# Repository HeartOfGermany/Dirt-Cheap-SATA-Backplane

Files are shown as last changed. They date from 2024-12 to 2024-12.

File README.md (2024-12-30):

# Dirt-Cheap-SATA-Backplane

## Front side (left/first) and back side

<picture>
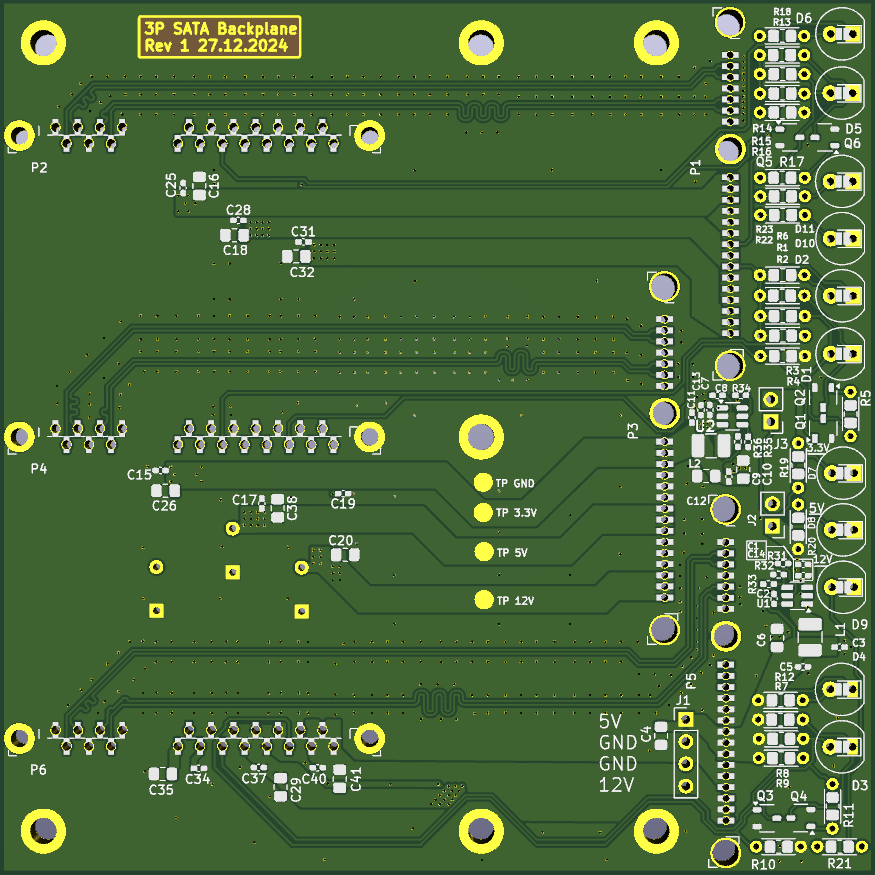
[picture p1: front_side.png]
Front side of the SATA Backplane
  
</picture>
<picture>
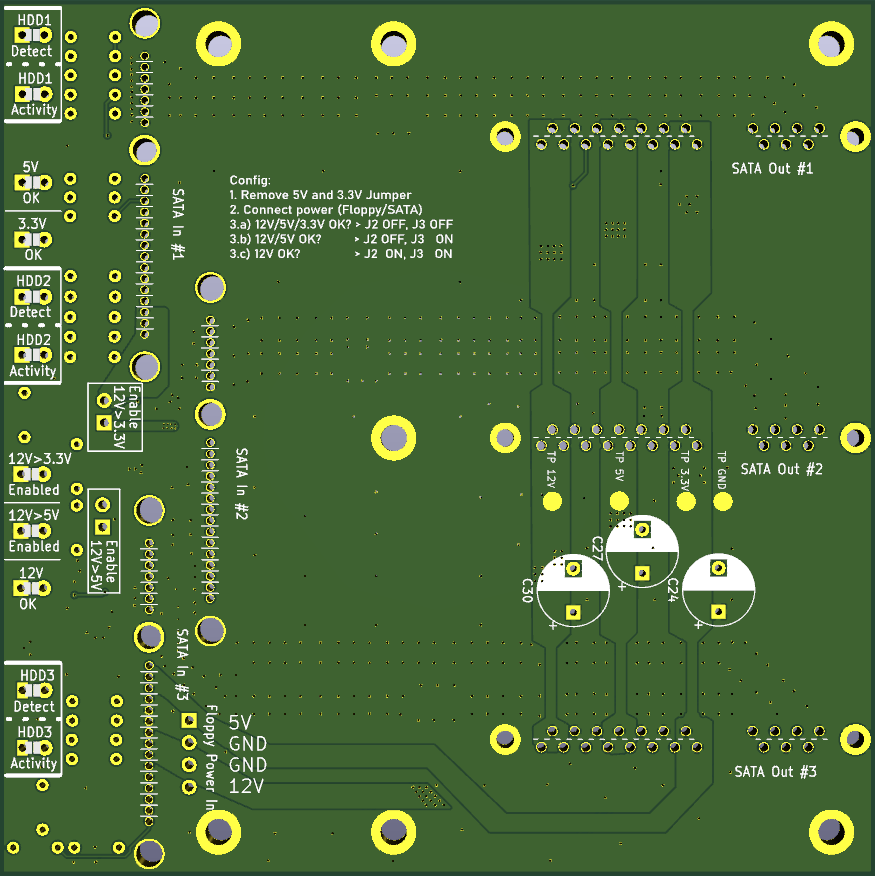
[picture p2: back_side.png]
Back side of the SATA Backplane
  
</picture>

This repo is intended to share plans for a super cheap DIY backplane. It is using KiCad and it fits the 100x100mm default of JLCPCB

Example: 100x100mm PCB x10pcs costs 15€ delivered to europe as the time of writing this. So 1 Backplane PCB costs just 1.50€ plus components. It uses 1.6mm 2 layer FR4.

## Features:
- LED Indicators
  - Activity LED (Bi-Color support!)
  - HDD Detect LED
  - 12V Power OK
  - 5V Power OK
  - 3.3V Power OK
  - 5V Power generator activated
  - 3.3V Power generator activated
- SATA or Floppy power input (or just solder your custom cable)
  - 12V only input (generate 5V and 3.3V automatically)
  - 12V+5V input (generate 3.3V automatically)
- Optional components
  - Do not need certain Indicators? Than leave them out
  - Do not need 5V or 3.3V generation? Than just do not solder in the converters
  - Just want to solder THT and NO SMD? Can do just that (But Activity LED requires 2 SOT23 transistors - but easier to solder than TO-92!
  - Just want to solder SMD? Also fine!
  - LED indicators to back side or front side? Do as you wish
  - Do not want to solder tons of decoupling? Just leave it out. It is optional and I only use the caps in the converter section of the schematic 

## How to use?
Steps:
1. Develop the board (JLCPCB worked fine for me)
2. Meanwhile order the Components, check the Schematic for purchasing links (no affiliate!)
3. Solder the components as you like
4. Test with an old HDD first!
5. Design some enclosure or cage, where you can screw the PCB onto the backside to slide it in and out again. After all... it is a Hot-Swap SATA Backplane. I used some wooden boards from an old drawer with some cut slots and a laser to get some ventilation slots. Than I used thin ply wood to mount the HDDs on (3mm max. recommended). These ply wood plates can slide in and out on the slotted boards, which form the surrounding. The uplink connectors are on the outside of the board. I will see if I will attach a reference image... Use your brain, it's not hard to build stuff!
6. How to nail alignment? The PCB has some mounting holes. Get yourself some flat standoffs and screw them in. Use some Alc to clean the backplate and the standoffs for adheasion. Now plug an upper and lower HDD in at least, to get the proper alignment. Use a dab of epoxy and just lay it on the backplate. The standoffs will glue in over the course of 24h (some gentle heat like 40-50°C speeds up a lot!) and you can than mount and unmount this as often by just unscrewing the screws (remember: after on comes off, so do not overtorque!). I recommend adding another layer to reinforce the joint and maybe even roughen the standoffs for better adheason, aswell as adding filler like quarz sand to the epoxy, to get a dang resilient, thick bond.

## Attention:
**DO**
- Use Flux. Tons of flux. If you are too cheap, use at least some Rosin intended for inhalation - it comes in 100g bags for just 2-3 bucks and is more efficient than those tiny containers with like 10g rosin.
- How to clean the flux residue easily? Use denatured Alc or Isopropyl to soak and than clean the board. You can also soak the board by wrapping in toilet paper and soaking it in Alc and leav it over night in a bag. Next day use tooth brush and carefully mobilize the rest of residues. Use some more to wash the rest away and your board will look like from factory
- Use enough heat! I make a lot of use of ground planes. Heat joints as fast as possible and go away to not damage components
- SATA connectors are hard to find on many proper stores, I got mine from Aliexpress - just double check the images to the PCB before ordering. The PCB allows some variation (Holes larger than needed). In theory you could also solder SMD equivalents in, if you can find some
- The Schematic contains a section "Parts List". A lot is from LCSC from China. It is like a dirt cheap Mouser/Digikey alternative, but of amazing quality. If you are cheap but want to ensure original components only, go there for your parts!
- Consider a Bismuth solder and some Amtech 559, if you are new to soldering. Requiring like 50K less temperature helps a LOT. It gives a ton of time to work on joints and constantly reflow, without overheating components (Especially ceramic caps are sensitive to re-heating a lot - could short)

**DON'T**
- Do not enable 3.3V or 5V generation, if your power input already supplies it! Check with the Voltage OK LEDs first! Otherwise the tiny buck converters try to provide 5V and 3.3V to your PC, which they cannot handle and they WILL overheat, potentially with permanent damage to the PCB.
- Do not use other thicknesses or materials than 1.6mm FR4!!! These could mess with the differential pair signalling, as the ground plane distance is very important to keep proper impedance
- Do NOT forget to use tons of flux. The PCB is easy to solder, if you use a decent cheap 60€/$ solder station with hot air, if Flux and Solder are good. Leaded solder helps a lot (though not healthy), or bismuth solder. Bismuth solder is a lot more brittle. Ensure, that the fillets form perfectly or rework them before use.

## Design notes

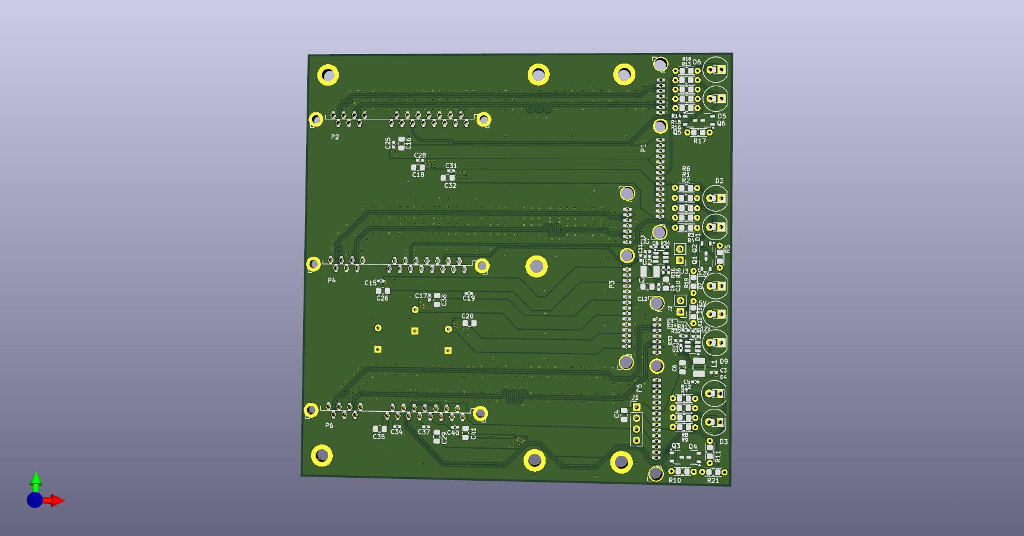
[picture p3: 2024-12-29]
sata_backplane.jpg

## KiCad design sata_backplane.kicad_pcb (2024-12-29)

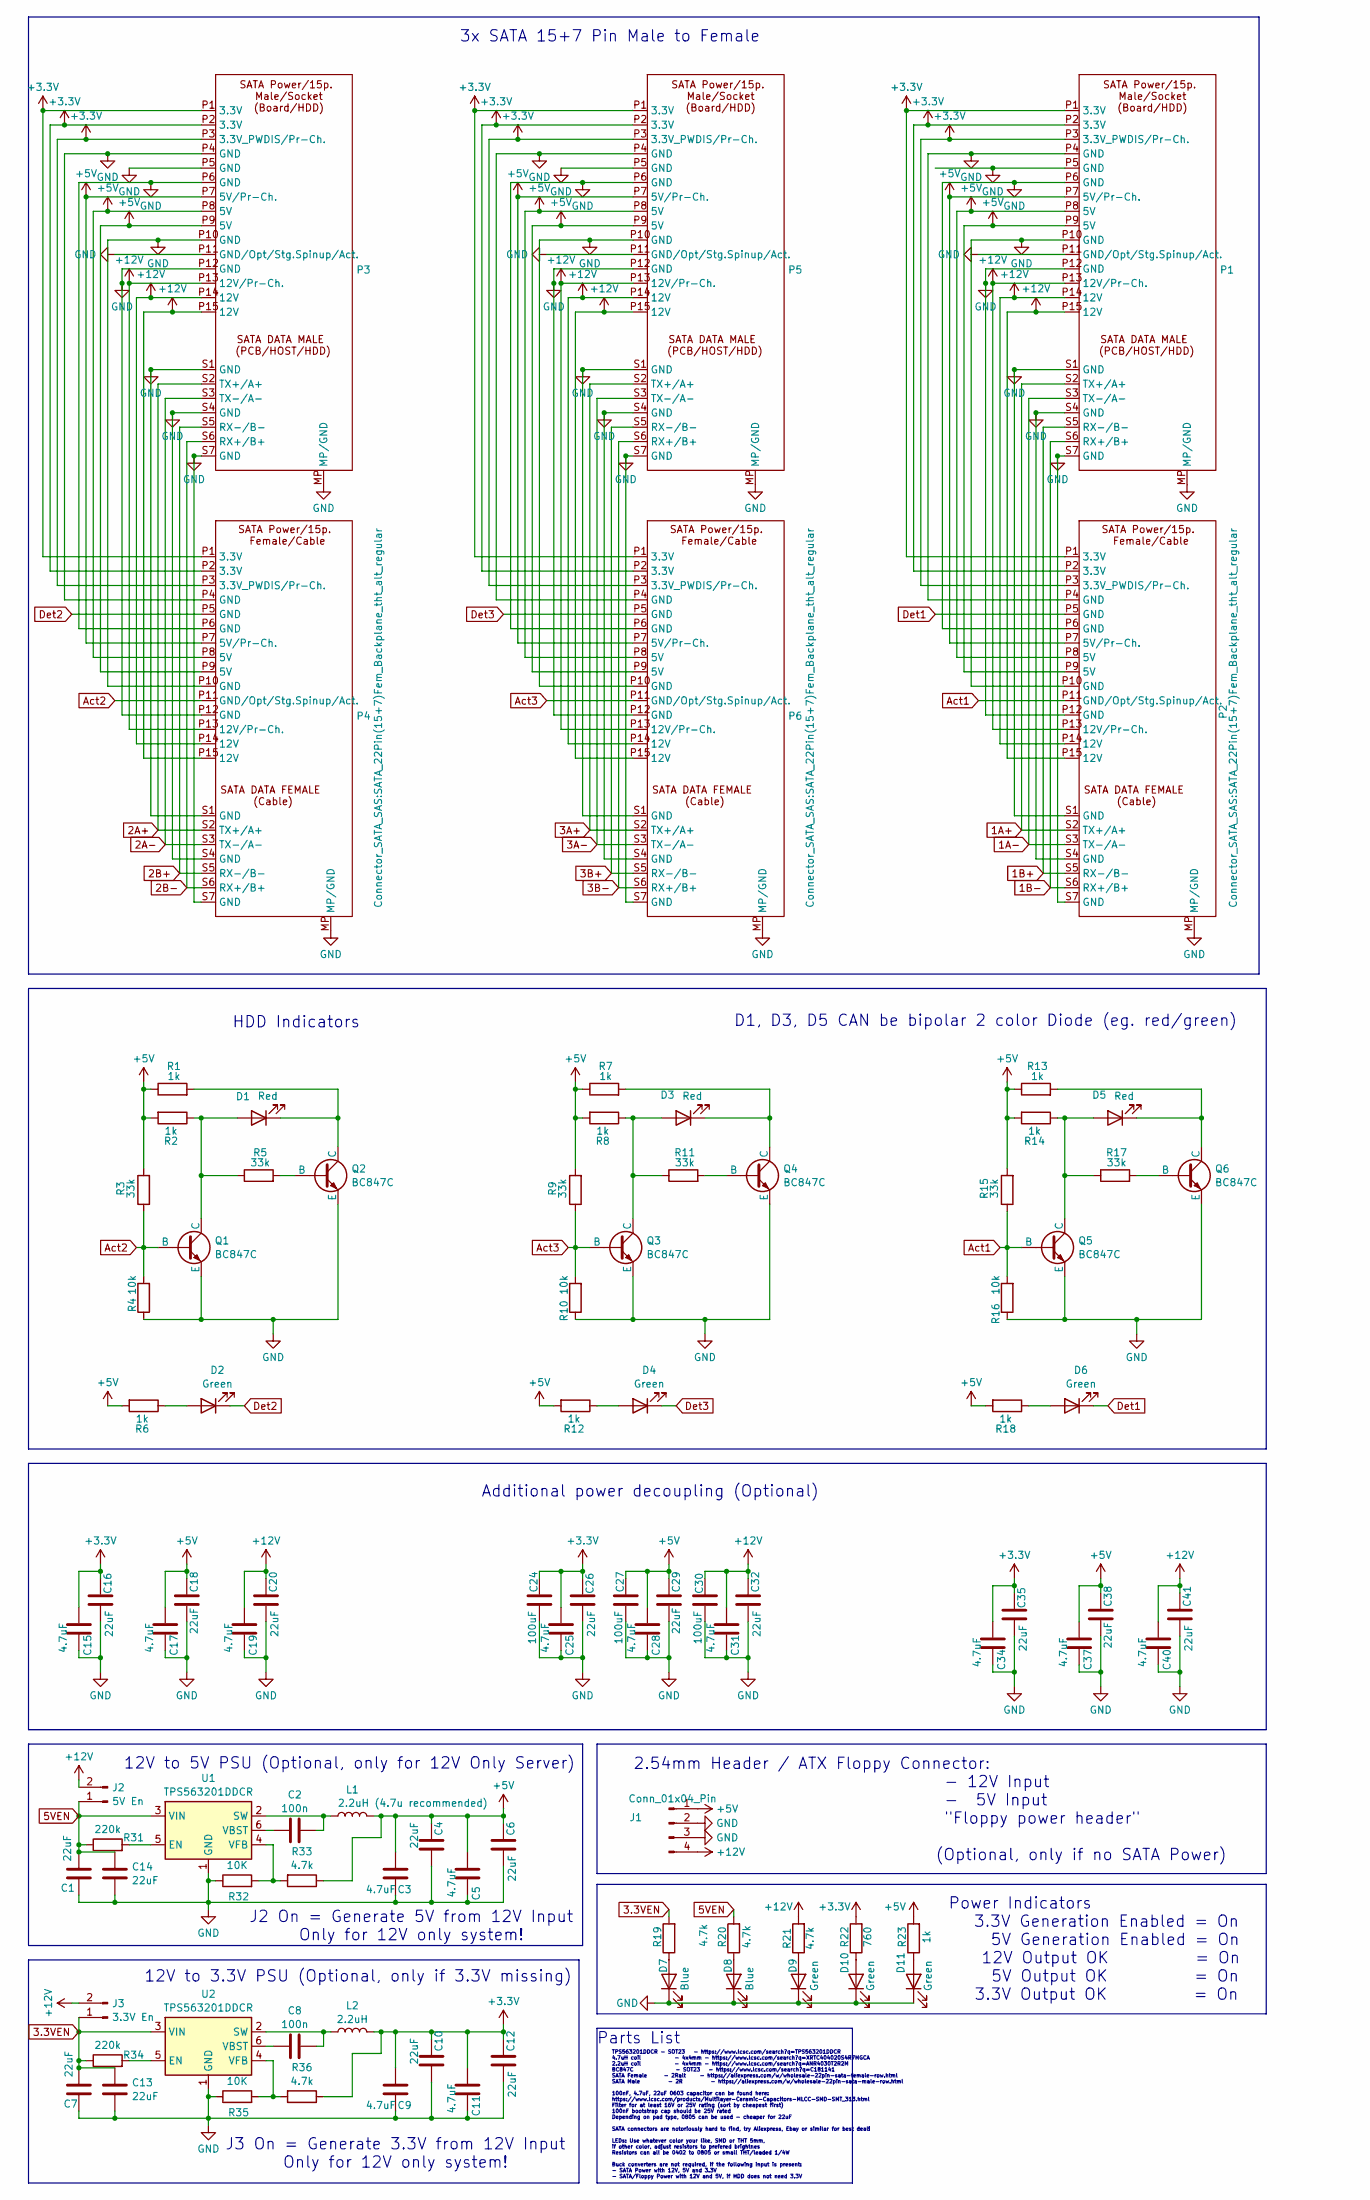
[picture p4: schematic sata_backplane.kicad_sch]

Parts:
C1, C7, C13, C14: 22uF; C_0402_1005Metric_Pad0.74x0.62mm_HandSolder
C2, C8: 100n; C_0402_1005Metric_Pad0.74x0.62mm_HandSolder
C3, C5, C9, C11, C15, C17, C19, C25, C28, C31, C34, C37, C40: 4.7uF; C_0402_1005Metric_Pad0.74x0.62mm_HandSolder
C4, C6, C10, C12, C16, C18, C20, C26, C29, C32, C35, C38, C41: 22uF; C_0805_2012Metric_Pad1.18x1.45mm_HandSolder
C24, C27, C30: 100uF; CP_Radial_D8.0mm_P5.00mm
D1, D3, D5: Red; Diode_SMD_THT_5mm_combi
D2, D4, D6, D9, D10, D11: Green; Diode_SMD_THT_5mm_combi
D7, D8: Blue; Diode_SMD_THT_5mm_combi
J1: Conn_01x04_Pin; PinHeader_1x04_P2.54mm_Vertical
J2: 5V En; PinHeader_1x02_P2.54mm_Vertical
J3: 3.3V En; PinHeader_1x02_P2.54mm_Vertical
L1: 2.2uH (4.7u recommended); L_1210_3225Metric_Pad1.42x2.65mm_HandSolder
L2: 2.2uH; L_1210_3225Metric_Pad1.42x2.65mm_HandSolder
P1, P3, P5: SATA_22Pin(15+7)Fem_Backplane_tht_lin
P2, P4, P6: SATA_22Pin(15+7)Fem_Backplane_tht_alt_regular
Q1, Q2, Q3, Q4, Q5, Q6: BC847C; SOT-23-3-Correct
R1, R2, R6, R7, R8, R12, R13, R14, R18, R23: 1k; R_Axial_L3.6_D1.6_P5.08_0805SMD_Combi
R3, R5, R9, R11, R15, R17: 33k; R_Axial_L3.6_D1.6_P5.08_0805SMD_Combi
R4, R10, R16: 10k; R_Axial_L3.6_D1.6_P5.08_0805SMD_Combi
R19, R20, R21: 4.7k; R_Axial_L3.6_D1.6_P5.08_0805SMD_Combi
R22: 760; R_Axial_L3.6_D1.6_P5.08_0805SMD_Combi
R31, R34: 220k; R_0402_1005Metric_Pad0.72x0.64mm_HandSolder
R32, R35: 10K; R_0402_1005Metric_Pad0.72x0.64mm_HandSolder
R33, R36: 4.7k; R_0402_1005Metric_Pad0.72x0.64mm_HandSolder
U1, U2: TPS563201DDCR; SOT-23-6

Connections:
1A+: P1.S2 (TX+/A+), P2.S2 (TX+/A+)
1A-: P1.S3 (TX-/A-), P2.S3 (TX-/A-)
1B+: P1.S5 (RX-/B-), P2.S5 (RX-/B-)
1B-: P1.S6 (RX+/B+), P2.S6 (RX+/B+)
2A+: P3.S2 (TX+/A+), P4.S2 (TX+/A+)
2A-: P3.S3 (TX-/A-), P4.S3 (TX-/A-)
2B+: P3.S5 (RX-/B-), P4.S5 (RX-/B-)
2B-: P3.S6 (RX+/B+), P4.S6 (RX+/B+)
3.3VEN: C7.2, C13.2, J3.1, R19.2, R34.1, U2.3 (VIN)
3A+: P5.S2 (TX+/A+), P6.S2 (TX+/A+)
3A-: P5.S3 (TX-/A-), P6.S3 (TX-/A-)
3B+: P5.S5 (RX-/B-), P6.S5 (RX-/B-)
3B-: P5.S6 (RX+/B+), P6.S6 (RX+/B+)
5VEN: C1.2, C14.2, J2.1, R20.2, R31.1, U1.3 (VIN)
+3.3V: C9.2, C10.2, C11.2, C12.2, C15.2, C16.2, C24.2, C25.2, C26.2, C34.2, C35.2, L2.2, P1.P1 (3.3V), P1.P2 (3.3V), P1.P3 (3.3V_PWDIS/Pr-Ch.), P2.P1 (3.3V), P2.P2 (3.3V), P2.P3 (3.3V_PWDIS/Pr-Ch.), P3.P1 (3.3V), P3.P2 (3.3V), P3.P3 (3.3V_PWDIS/Pr-Ch.), P4.P1 (3.3V), P4.P2 (3.3V), P4.P3 (3.3V_PWDIS/Pr-Ch.), P5.P1 (3.3V), P5.P2 (3.3V), P5.P3 (3.3V_PWDIS/Pr-Ch.), P6.P1 (3.3V), P6.P2 (3.3V), P6.P3 (3.3V_PWDIS/Pr-Ch.), R22.2, R36.1
+5V: C3.2, C4.2, C5.2, C6.2, C17.2, C18.2, C27.2, C28.2, C29.2, C37.2, C38.2, J1.1, L1.2, P1.P7 (5V/Pr-Ch.), P1.P8 (5V), P1.P9 (5V), P2.P7 (5V/Pr-Ch.), P2.P8 (5V), P2.P9 (5V), P3.P7 (5V/Pr-Ch.), P3.P8 (5V), P3.P9 (5V), P4.P7 (5V/Pr-Ch.), P4.P8 (5V), P4.P9 (5V), P5.P7 (5V/Pr-Ch.), P5.P8 (5V), P5.P9 (5V), P6.P7 (5V/Pr-Ch.), P6.P8 (5V), P6.P9 (5V), R1.1, R2.2, R3.2, R6.2, R7.1, R8.2, R9.2, R12.2, R13.1, R14.2, R15.2, R18.2, R23.2, R33.1
+12V: C19.2, C20.2, C30.2, C31.2, C32.2, C40.2, C41.2, J1.4, J2.2, J3.2, P1.P13 (12V/Pr-Ch.), P1.P14 (12V), P1.P15 (12V), P2.P13 (12V/Pr-Ch.), P2.P14 (12V), P2.P15 (12V), P3.P13 (12V/Pr-Ch.), P3.P14 (12V), P3.P15 (12V), P4.P13 (12V/Pr-Ch.), P4.P14 (12V), P4.P15 (12V), P5.P13 (12V/Pr-Ch.), P5.P14 (12V), P5.P15 (12V), P6.P13 (12V/Pr-Ch.), P6.P14 (12V), P6.P15 (12V), R21.2
Act1: P2.P11 (GND/Opt/Stg.Spinup/Act.), Q5.2 (B), R15.1, R16.2
Act2: P4.P11 (GND/Opt/Stg.Spinup/Act.), Q1.2 (B), R3.1, R4.2
Act3: P6.P11 (GND/Opt/Stg.Spinup/Act.), Q3.2 (B), R9.1, R10.2
Det1: D6.1 (K), P2.P5 (GND)
Det2: D2.1 (K), P4.P5 (GND)
Det3: D4.1 (K), P6.P5 (GND)
GND: C1.1, C3.1, C4.1, C5.1, C6.1, C7.1, C9.1, C10.1, C11.1, C12.1, C13.1, C14.1, C15.1, C16.1, C17.1, C18.1, C19.1, C20.1, C24.1, C25.1, C26.1, C27.1, C28.1, C29.1, C30.1, C31.1, C32.1, C34.1, C35.1, C37.1, C38.1, C40.1, C41.1, D7.1 (K), D8.1 (K), D9.1 (K), D10.1 (K), D11.1 (K), J1.2, J1.3, P1.MP (MP/GND), P1.P4 (GND), P1.P5 (GND), P1.P6 (GND), P1.P10 (GND), P1.P11 (GND/Opt/Stg.Spinup/Act.), P1.P12 (GND), P1.S1 (GND), P1.S4 (GND), P1.S7 (GND), P2.MP (MP/GND), P2.P4 (GND), P2.P6 (GND), P2.P10 (GND), P2.P12 (GND), P2.S1 (GND), P2.S4 (GND), P2.S7 (GND), P3.MP (MP/GND), P3.P4 (GND), P3.P5 (GND), P3.P6 (GND), P3.P10 (GND), P3.P11 (GND/Opt/Stg.Spinup/Act.), P3.P12 (GND), P3.S1 (GND), P3.S4 (GND), P3.S7 (GND), P4.MP (MP/GND), P4.P4 (GND), P4.P6 (GND), P4.P10 (GND), P4.P12 (GND), P4.S1 (GND), P4.S4 (GND), P4.S7 (GND), P5.MP (MP/GND), P5.P4 (GND), P5.P5 (GND), P5.P6 (GND), P5.P10 (GND), P5.P11 (GND/Opt/Stg.Spinup/Act.), P5.P12 (GND), P5.S1 (GND), P5.S4 (GND), P5.S7 (GND), P6.MP (MP/GND), P6.P4 (GND), P6.P6 (GND), P6.P10 (GND), P6.P12 (GND), P6.S1 (GND), P6.S4 (GND), P6.S7 (GND), Q1.3 (E), Q2.3 (E), Q3.3 (E), Q4.3 (E), Q5.3 (E), Q6.3 (E), R4.1, R10.1, R16.1, R32.1, R35.1, U1.1 (GND), U2.1 (GND)
unnamed: D1.2 (A), Q1.1 (C), R2.1, R5.1
unnamed: D1.1 (K), Q2.1 (C), R1.2
unnamed: D2.2 (A), R6.1
unnamed: D3.2 (A), Q3.1 (C), R8.1, R11.1
unnamed: D3.1 (K), Q4.1 (C), R7.2
unnamed: D4.2 (A), R12.1
unnamed: D5.2 (A), Q5.1 (C), R14.1, R17.1
unnamed: D5.1 (K), Q6.1 (C), R13.2
unnamed: D6.2 (A), R18.1
unnamed: D7.2 (A), R19.1
unnamed: D8.2 (A), R20.1
unnamed: D9.2 (A), R21.1
unnamed: D10.2 (A), R22.1
unnamed: D11.2 (A), R23.1
unnamed: Q2.2 (B), R5.2
unnamed: Q4.2 (B), R11.2
unnamed: Q6.2 (B), R17.2
unnamed: R31.2, U1.5 (EN)
unnamed: C2.1, L1.1, U1.2 (SW)
unnamed: C2.2, U1.6 (VBST)
unnamed: R32.2, R33.2, U1.4 (VFB)
unnamed: R34.2, U2.5 (EN)
unnamed: C8.1, L2.1, U2.2 (SW)
unnamed: C8.2, U2.6 (VBST)
unnamed: R35.2, R36.2, U2.4 (VFB)

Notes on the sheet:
J2 On = Generate 5V from 12V Input Only for 12V only system!
J3 On = Generate 3.3V from 12V Input Only for 12V only system!
12V to 5V PSU (Optional, only for 12V Only Server)
TPS563201DDCR - SOT23 - https://www.lcsc.com/search?q=TPS563201DDCR 4.7uH coil - 4x4mm - https://www.lcsc.com/search?q=XRTC404020S4R7MGCA 2.2uH coil - 4x4mm - https://www.lcsc.com/search?q=ANR4030T2R2M BC847C - SOT23 - https://www.lcsc.com/search?q=C181141 SATA Female - 2Ralt - https://aliexpress.c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
D1, D3, D5 CAN be bipolar 2 color Diode (eg. red/green)
HDD Indicators
Parts List
3x SATA 15+7 Pin Male to Female
12V to 3.3V PSU (Optional, only if 3.3V missing)
Power Indicators 3.3V Generation Enabled = On 5V Generation Enabled = On 12V Output OK = On 5V Output OK = On 3.3V Output OK = On
2.54mm Header / ATX Floppy Connector: - 12V Input - 5V Input "Floppy power header" (Optional, only if no SATA Power)
Additional power decoupling (Optional)

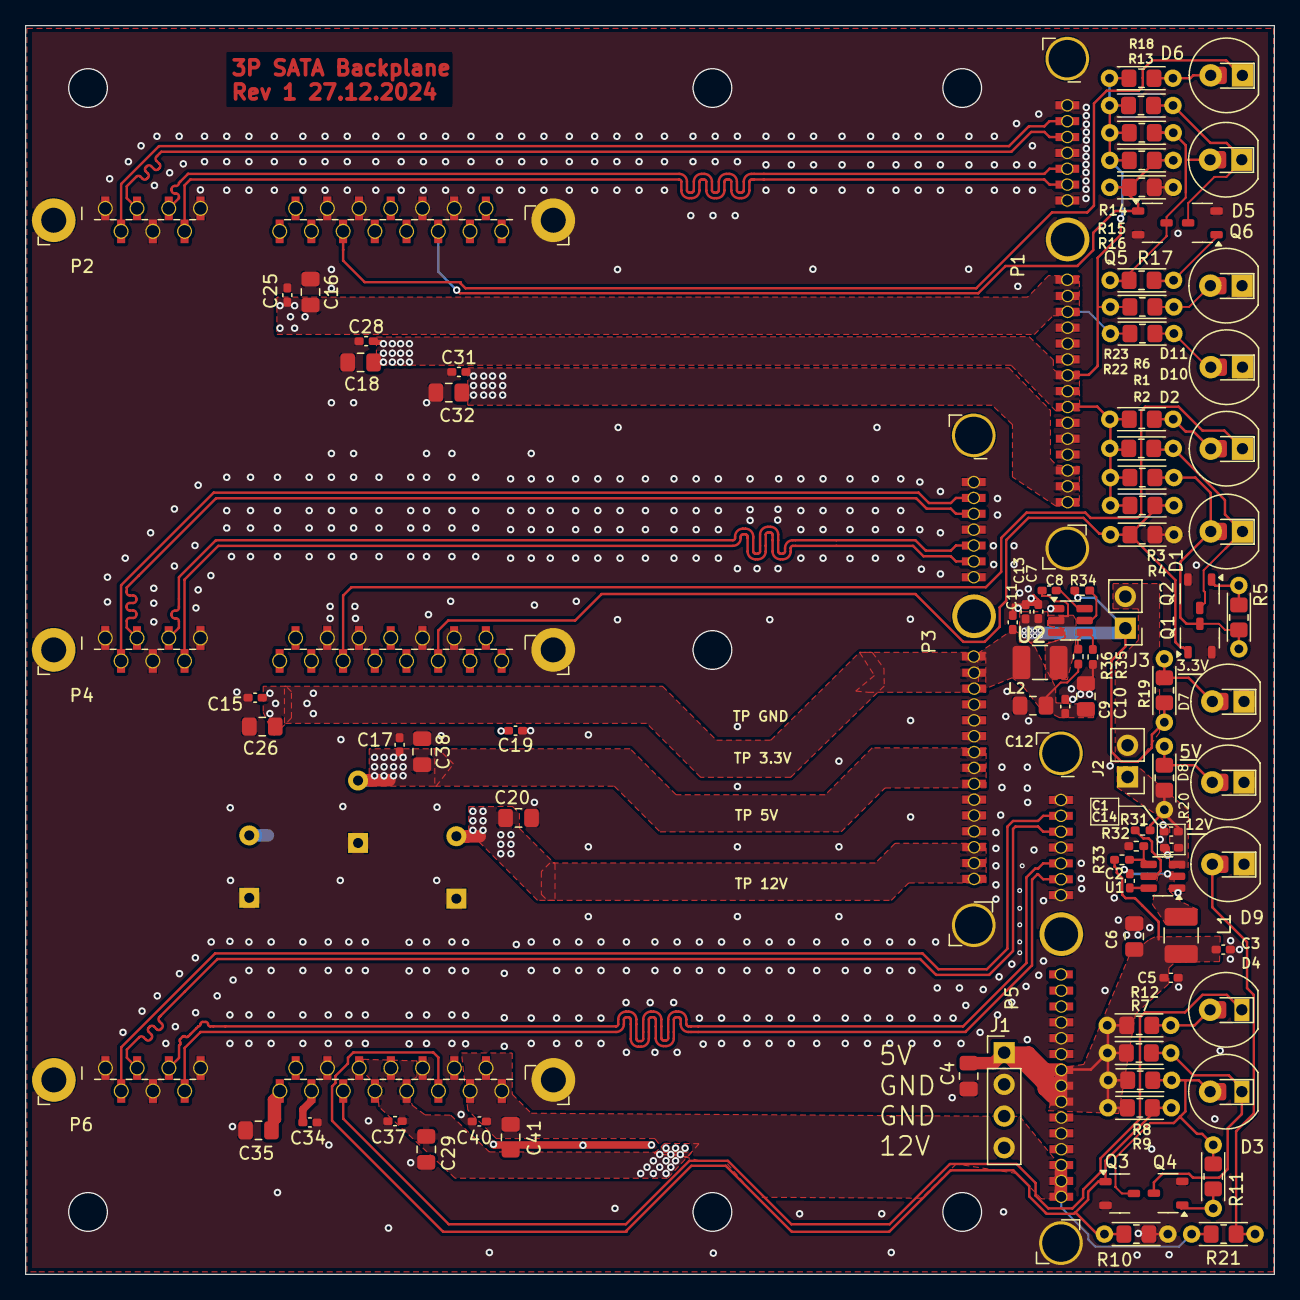
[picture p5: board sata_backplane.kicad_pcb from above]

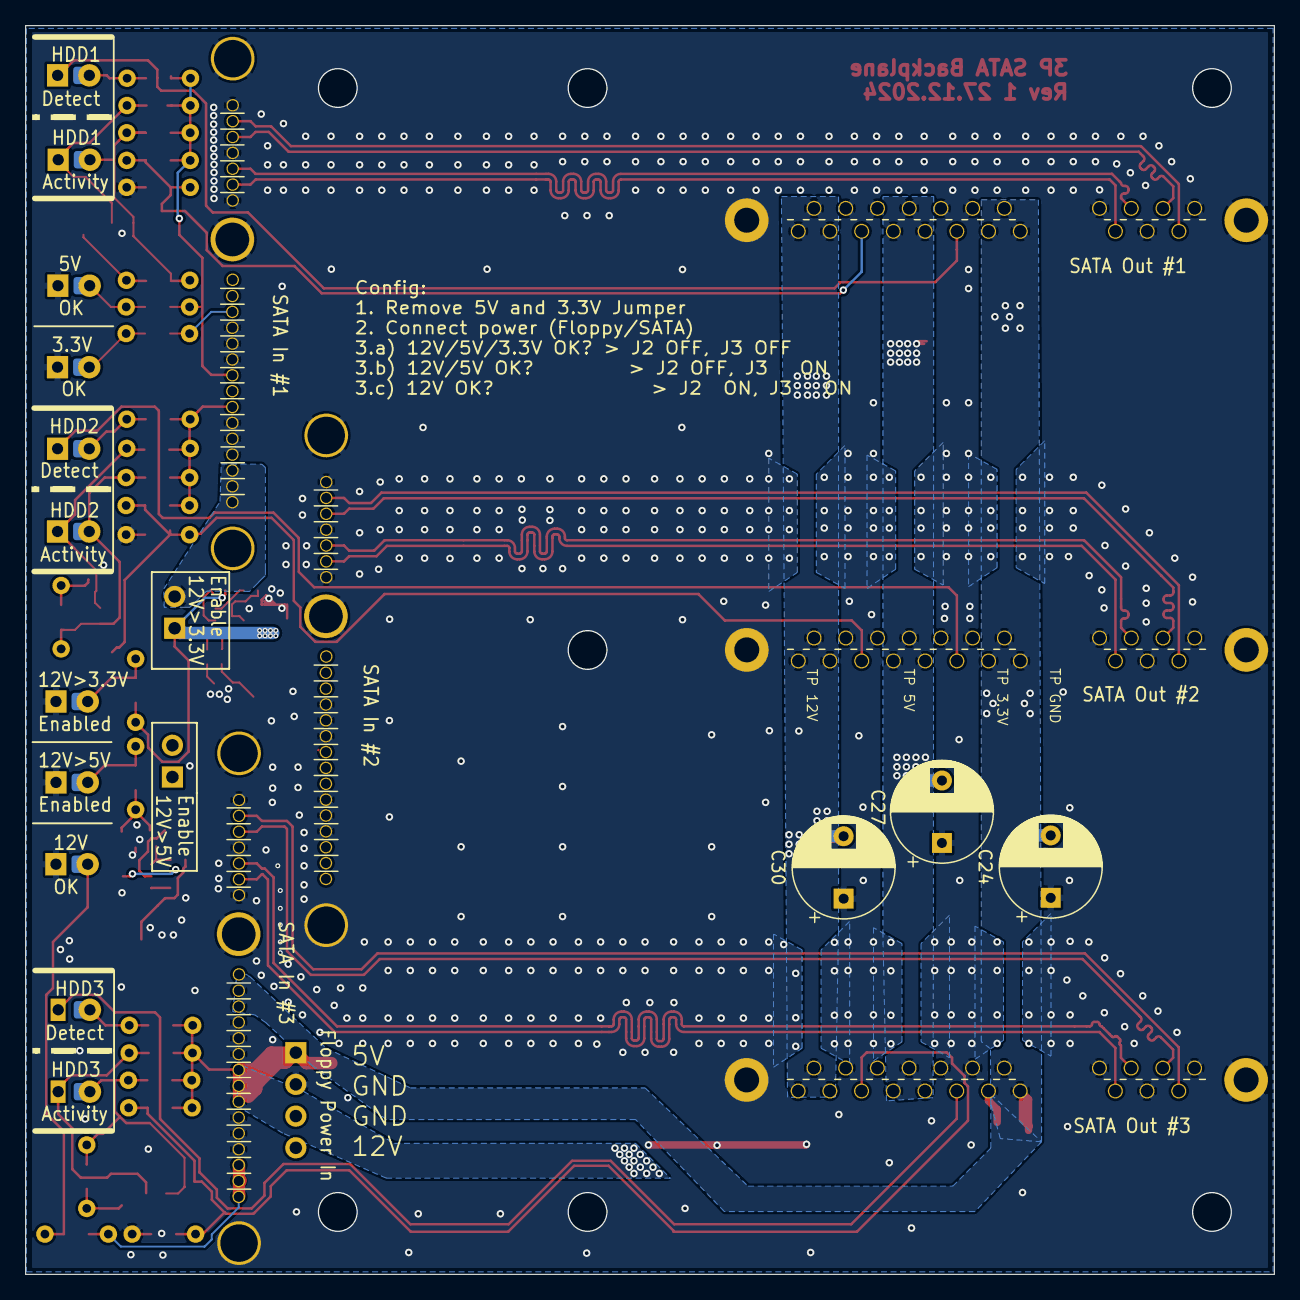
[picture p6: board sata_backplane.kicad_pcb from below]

Board: 2 copper layers, 100.0 x 100.0 mm, 94 parts (3 on the bottom side), 49 nets.

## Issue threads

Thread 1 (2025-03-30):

Do you have the bom files?

laleeroy, 2025-03-30:

HeartOfGermany, 2025-03-30:
Not really. The board is designed, so you can use whatever compatible component you have lying around. The recommendation on what component you CAN use is in the Schematic file in a small text field. This resembles the source that I have used. You can use pretty much every pin compatible component and you can also ommit ALL components and just solder the sata connecters on, if you want. That was the goal of this board.

Closed 2025-03-30.
